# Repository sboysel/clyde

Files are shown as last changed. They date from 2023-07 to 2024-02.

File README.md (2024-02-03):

# clyde




- split ortholinear
- MX 36 keys (layout inspired by [weteor/Kong](https://github.com/weteor/Kong))
- RJ45 split comms
- WeAct RP2040 Pi Pico
- PCB: diodeless, reversible, hotswap

See `BOM` for complete list of parts and relevant numbers. Gerbers for PCB and switch plate in `prod`. Outline for bottom plate in `ergogen/outlines`.

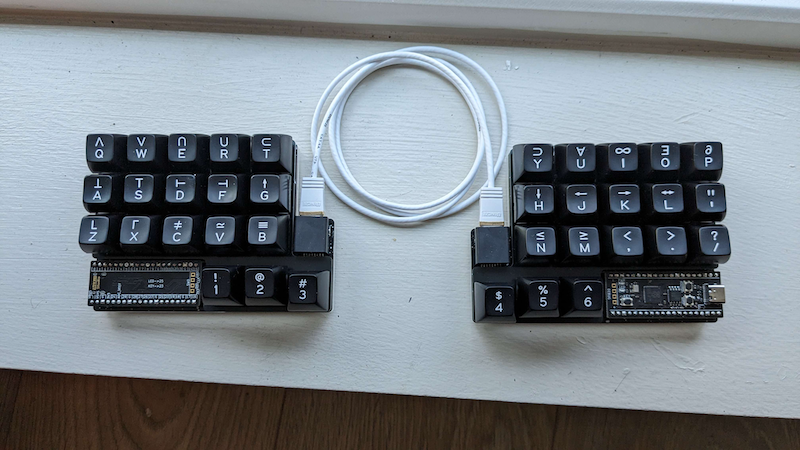
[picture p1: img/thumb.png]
clyde


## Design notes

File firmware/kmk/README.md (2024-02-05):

# clyde kmk firmware

1. copy CircuitPython to Pi Picos
2. rename L and R
    ```
    sudo umount /dev/sdb1
    sudo fatlabel /dev/sdb1 CLYDE36L
    ...
    ```
3. Use Piantor firmware as a starting point
    - https://raw.githubusercontent.com/cairnm/kmk_firmware/piantor/boards/beekeeb/piantor/kb.py
    - https://raw.githubusercontent.com/cairnm/kmk_firmware/piantor/boards/beekeeb/piantor/main.py 

## docs

- https://circuitpython.org/board/weact_studio_pico/
- http://kmkfw.io/docs/split_keyboards/

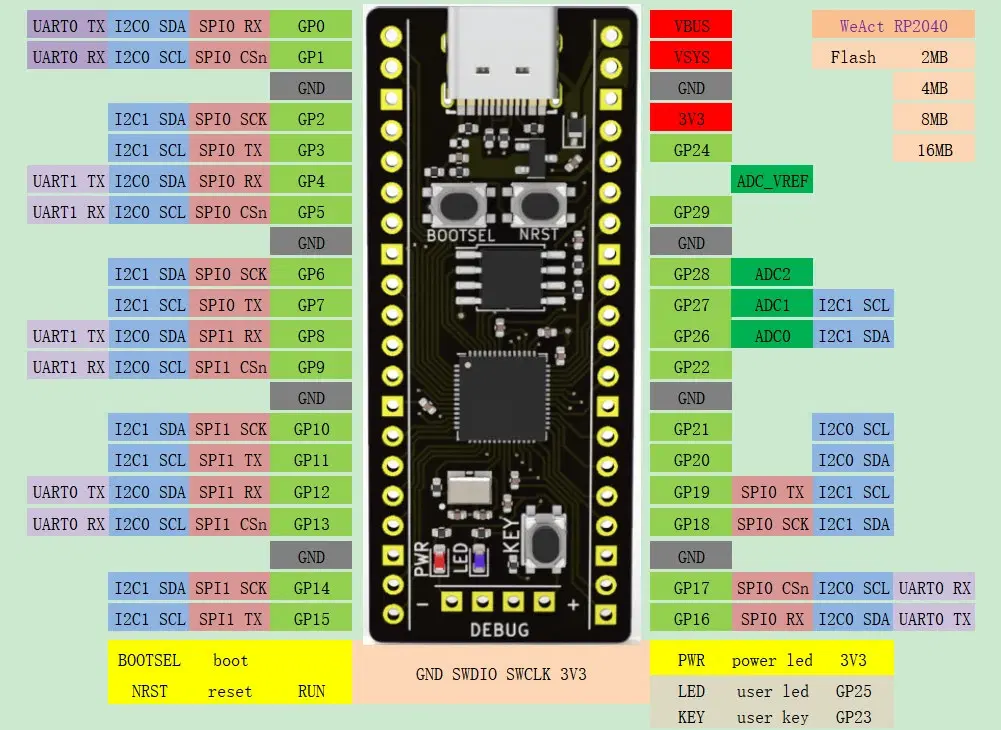
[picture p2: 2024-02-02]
img/WeAct_RP2040.jpg

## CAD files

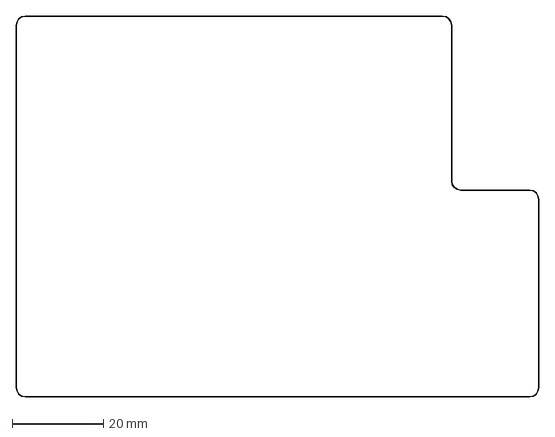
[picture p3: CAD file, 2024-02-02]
ergogen/outlines/clyde-pcb.dxf
114.3 x 83.3 mm

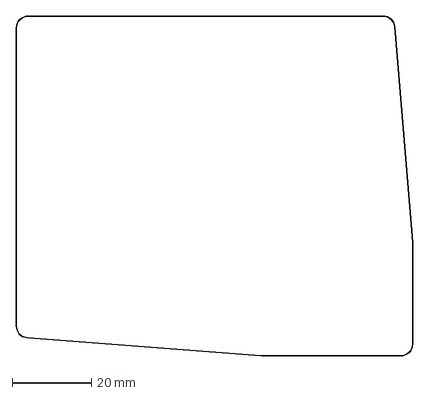
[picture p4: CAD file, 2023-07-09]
mx/outlines/clyde-mx-bottom-plate.dxf
100.0 x 85.7 mm

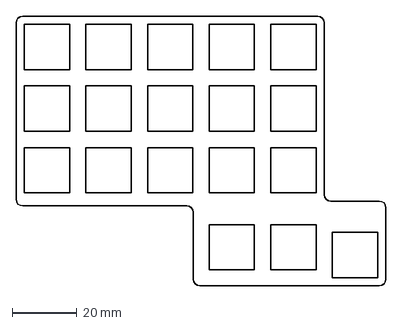
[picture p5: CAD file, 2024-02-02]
ergogen/outlines/clyde-switch-plate.dxf
114.3 x 83.3 mm

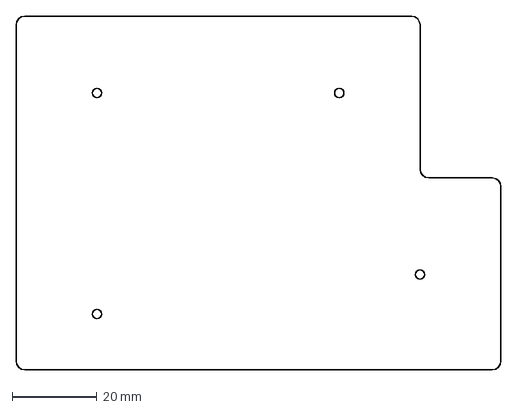
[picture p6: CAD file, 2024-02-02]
ergogen/outlines/clyde-bottom-plate.dxf
114.3 x 83.3 mm

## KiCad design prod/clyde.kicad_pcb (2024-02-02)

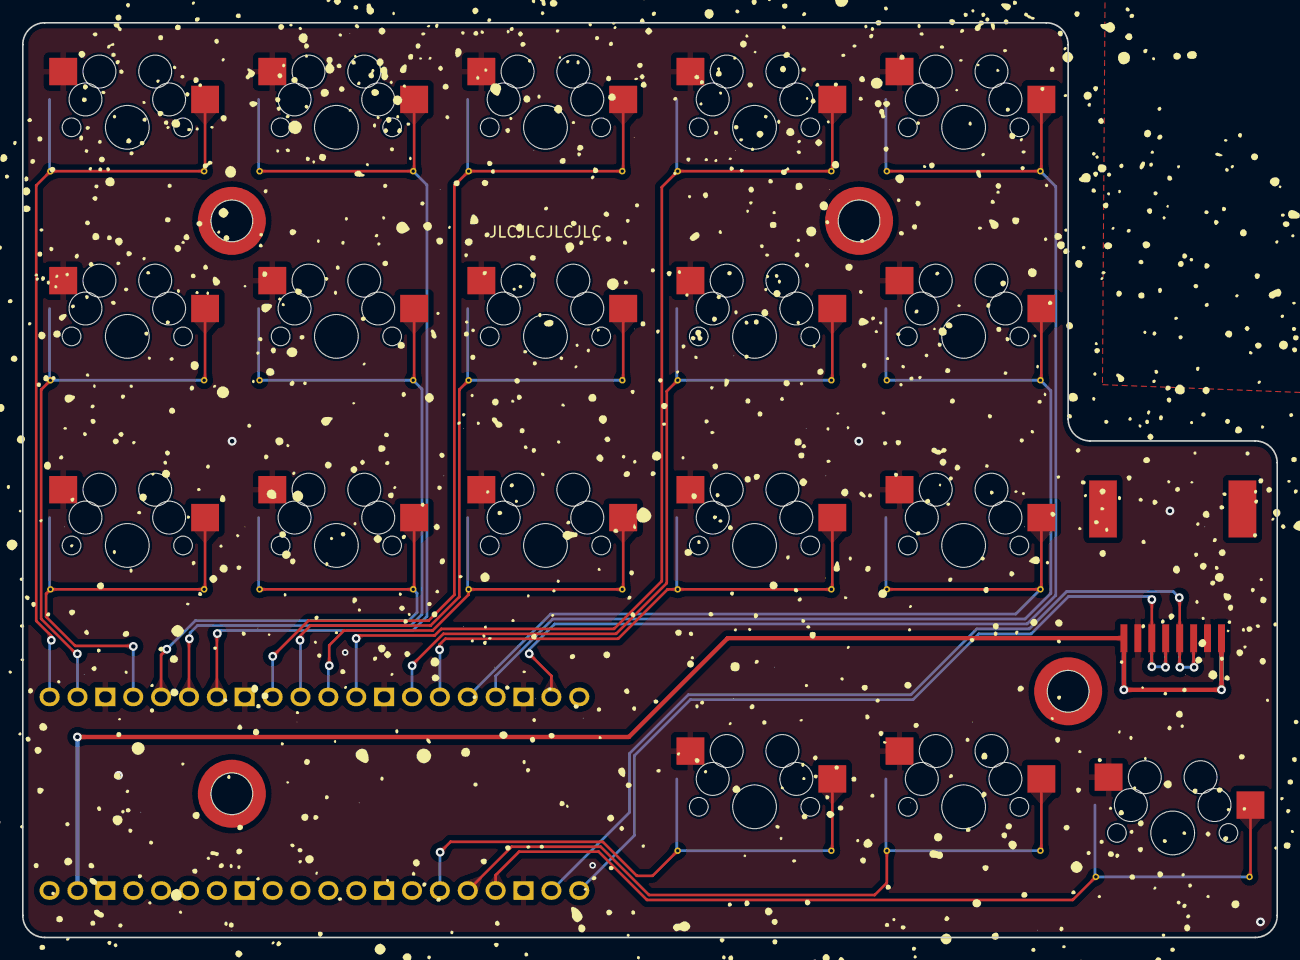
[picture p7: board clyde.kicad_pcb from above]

Board: 2 copper layers, 114.3 x 83.3 mm, 19 parts (0 on the bottom side), 19 nets.

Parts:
S1, S2, S3, S4, S5, S6, S7, S8, S9, S10, S11, S12, S13, S14, S15, S16, S17, S18: MX
U0: RPi_Pico_TH_oval_face_down

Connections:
GND: S1.2, S2.2, S3.2, S4.2, S5.2, S6.2, S7.2, S8.2, S9.2, S10.2, S11.2, S12.2, S13.2, S14.2, S15.2, S16.2, S17.2, S18.2, U0.3, U0.8, U0.13, U0.18, U0.23, U0.28, U0.33, U0.38
matrix_index_bottom: S10.1, U0.15
matrix_index_home: S11.1, U0.14
matrix_index_top: S12.1, U0.12
matrix_inner_bottom: S13.1, U0.16
matrix_inner_home: S14.1, U0.17
matrix_inner_top: S15.1, U0.19
matrix_middle_bottom: S7.1, U0.11
matrix_middle_home: S8.1, U0.10
matrix_middle_top: S9.1, U0.9
matrix_pinky_bottom: S1.1, U0.4
matrix_pinky_home: S2.1, U0.2
matrix_pinky_top: S3.1, U0.1
matrix_ring_bottom: S4.1, U0.5
matrix_ring_home: S5.1, U0.6
matrix_ring_top: S6.1, U0.7
thumb_far_mods: S18.1, U0.24
thumb_middle_mods: S17.1, U0.25
thumb_near_mods: S16.1, U0.26

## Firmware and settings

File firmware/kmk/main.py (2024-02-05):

import board

from kb import KMKKeyboard, isRight
keyboard = KMKKeyboard()

from kmk.keys import KC
from kmk.modules.split import Split, SplitSide, SplitType
from kmk.modules.layers import Layers; keyboard.modules.append(Layers())
from kmk.modules.modtap import ModTap; keyboard.modules.append(ModTap())
from kmk.modules.mouse_keys import MouseKeys; keyboard.modules.append(MouseKeys())
from kmk.modules.power import Power; keyboard.modules.append(Power())
from kmk.modules.tapdance import TapDance; keyboard.modules.append(TapDance())
from kmk.extensions.media_keys import MediaKeys; keyboard.extensions.append(MediaKeys())
from kmk.modules.capsword import CapsWord; keyboard.modules.append(CapsWord())

keyboard.tap_time = 100

split_side = SplitSide.RIGHT if isRight else SplitSide.LEFT

split = Split(
    split_side=split_side,
    split_type=SplitType.UART,
    split_flip=True,
    split_target_left=True,
    uart_flip=False,
    data_pin=board.GP17,
    data_pin2=board.GP16,
    use_pio=True,
)
keyboard.modules.append(split)


# === layer tap ---------------------------------------------------------------
# NAV (layer 1)
LT_TAB = KC.LT(1, KC.TAB, prefer_hold=True, tap_interrupted=False, tap_time=200)
LT_SPC = KC.LT(1, KC.SPC, prefer_hold=True, tap_interrupted=False, tap_time=200)
# NUM (layer 2)
LT_BSPC = KC.LT(2, KC.BSPC, prefer_hold=True, tap_interrupted=False, tap_time=200)
# SYM (layer 3)
LT_ENT = KC.LT(3, KC.ENT, prefer_hold=True, tap_interrupted=False, tap_time=200)
# FUN (layer 4)
LT_DEL = KC.LT(4, KC.DEL, prefer_hold=True, tap_interrupted=False, tap_time=200)
# MEDIA (layer 5)
LT_ESC = KC.LT(5, KC.ESC, prefer_hold=True, tap_interrupted=False, tap_time=200)

# === home row mods ------------------------------------------------------------
MT_A = KC.MT(KC.A, KC.LGUI, prefer_hold=False, tap_interrupted=True, tap_time=200)
MT_S = KC.MT(KC.S, KC.LALT, prefer_hold=False, tap_interrupted=True, tap_time=200)
MT_D = KC.MT(KC.D, KC.LCTL, prefer_hold=False, tap_interrupted=True, tap_time=200)
MT_F = KC.MT(KC.F, KC.LSFT, prefer_hold=False, tap_interrupted=True, tap_time=200)

MT_J = KC.MT(KC.J, KC.LSFT, prefer_hold=False, tap_interrupted=True, tap_time=200)
MT_K = KC.MT(KC.K, KC.LCTL, prefer_hold=False, tap_interrupted=True, tap_time=200)
MT_L = KC.MT(KC.L, KC.LALT, prefer_hold=False, tap_interrupted=True, tap_time=200)
MT_QUOT = KC.MT(KC.QUOT, KC.LGUI, prefer_hold=False, tap_interrupted=True, tap_time=200)

# === keymap -------------------------------------------------------------------
keyboard.keymap = [
    # QWERTY
    [
        KC.Q,    KC.W,    KC.E,    KC.R,    KC.T,       KC.Y,   KC.U,    KC.I,    KC.O,    KC.P,
        MT_A,    MT_S,    MT_D,    MT_F,    KC.G,       KC.H,   MT_J,    MT_K,    MT_L,    MT_QUOT,
        KC.Z,    KC.X,    KC.C,    KC.V,    KC.B,       KC.N,   KC.M,    KC.COMM, KC.DOT,  KC.SLSH,
                          LT_ESC,  LT_SPC,  LT_TAB,     LT_ENT, LT_BSPC, LT_DEL,
    ],                  
    #                     MEDIA             NAV         NUM     SYM      FUN
    # NAV
    [
        KC.NO,   KC.NO,   KC.NO,   KC.NO,   KC.NO,      KC.NO,  KC.NO,   KC.NO,   KC.NO,   KC.NO,
        KC.LGUI, KC.LALT, KC.LCTL, KC.LSFT, KC.NO,      KC.NO,  KC.LEFT, KC.DOWN, KC.UP,   KC.RGHT,
        KC.NO,   KC.RALT, KC.NO,   KC.NO,   KC.NO,      KC.INS, KC.HOME, KC.PGDN, KC.PGUP, KC.END,
                          KC.NO,   KC.NO,   KC.NO,      KC.ENT, KC.BSPC, KC.DEL, 
    ],
    # NUM
    [
        KC.LBRC, KC.N7,   KC.N8,   KC.N9,   KC.RBRC,    KC.NO,  KC.NO,   KC.NO,   KC.NO,   KC.NO,
        KC.SCLN, KC.N4,   KC.N5,   KC.N6,   KC.EQL,     KC.NO,  KC.LSFT, KC.LCTL, KC.LALT, KC.LGUI,
        KC.GRV,  KC.N1,   KC.N2,   KC.N3,   KC.BSLS,    KC.NO,  KC.NO,   KC.NO,   KC.RALT, KC.NO,
                          KC.DOT,  KC.N0,   KC.MINS,    KC.NO,  KC.NO,   KC.NO,
    ],
    # SYM
    [
        KC.LCBR, KC.AMPR, KC.ASTR, KC.LPRN, KC.RCBR,    KC.NO,  KC.NO,   KC.NO,   KC.NO,   KC.NO,
        KC.COLN, KC.DLR,  KC.PERC, KC.CIRC, KC.PLUS,    KC.NO,  KC.LSFT, KC.LCTL, KC.LALT, KC.LGUI,
        KC.TILD, KC.EXLM, KC.AT,   KC.HASH, KC.PIPE,    KC.NO,  KC.NO,   KC.NO,   KC.RALT, KC.NO,
                          KC.LPRN, KC.RPRN, KC.UNDS,    KC.NO,  KC.NO,   KC.NO,
    ],
    # FUN
    [
        KC.F12,  KC.F7,   KC.F8,   KC.F9,   KC.PSCR,    KC.NO,  KC.NO,   KC.NO,   KC.NO,   KC.NO,
        KC.F11,  KC.F4,   KC.F5,   KC.F6,   KC.SLCK,    KC.NO,  KC.LSFT, KC.LCTL, KC.LALT, KC.LGUI,
        KC.F10,  KC.F1,   KC.F2,   KC.F3,   KC.PAUS,    KC.NO,  KC.NO,   KC.NO,   KC.RALT, KC.NO,
                          KC.APP,  KC.SPC,  KC.TAB,     KC.NO,  KC.NO,   KC.NO,
    ],
    # MEDIA
    [
        KC.NO,   KC.NO,   KC.NO,   KC.NO,   KC.NO,      KC.NO,     KC.NO,   KC.NO,   KC.NO,   KC.NO,
        KC.LGUI, KC.LALT, KC.LCTL, KC.LSFT, KC.NO,      KC.PS_TOG, KC.MPRV, KC.VOLD, KC.VOLU, KC.MNXT,
        KC.NO,   KC.RALT, KC.NO,   KC.NO,   KC.NO,      KC.HID,    KC.NO,   KC.NO,   KC.NO,   KC.NO,
                          KC.NO,   KC.NO,   KC.NO,      KC.MSTP,   KC.MPLY, KC.MUTE,
    ],
]

layer_names_list = [
    'QWERTY', 'NAV', 'NUM', 'SYM', 'FUN', 'MEDIA',
]

if __name__ == '__main__':
    keyboard.go()

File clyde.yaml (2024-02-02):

meta:
  engine: 4.0.4
  name: clyde
  version: 1.0.0
  author: sboysel
  url: https://github.com/sboysel/clyde

units:
  kx: U
  ky: U
  px: 0.5kx
  py: 0.5ky
  tx: 0
  ty: 0.25ky
  ts: 0.125ky
  vx: 7
  vy: -4
  pcb_fillet: 2
  case_fillet: 2
  case_thickness: 6

points:
  zones:
    matrix:
      anchor:
        shift: [8kx, -8ky]
      columns:
        pinky:
        ring:
        middle:
        index:
        inner:
      rows:
        bottom:
        home:
        top:
    thumb:
      anchor:
        ref: matrix_index_bottom
        shift: [tx, -1ky - ty]
      columns:
        near:
        middle:
        far:
          key:
            stagger: -ts
      rows:
        mods:
  key:
    padding: 1ky
    spread: 1kx

outlines:
  _pcb:
    - what: polygon
      points:
        # NW
        - ref: matrix_pinky_top
          shift: [-px, py]
        # NE
        - ref: matrix_inner_top
          shift: [px, py]
        # E
        - ref: matrix_inner_bottom
          shift: [px, py]
        - ref: matrix_inner_bottom
          shift: [px + kx, py]
        # SE
        - ref: thumb_far_mods
          shift: [px, -py]
        - ref: thumb_near_mods
          shift: [-px, -py - ts]
        # SW
        - ref: matrix_pinky_bottom
          shift: [-px, -ky - ty - py - ts]
  _plate:
    - what: polygon
      points:
        # NW
        - ref: matrix_pinky_top
          shift: [-px, py]
        # NE
        - ref: matrix_inner_top
          shift: [px, py]
        # E
        - ref: matrix_inner_bottom
          shift: [px, -py]
        - ref: matrix_inner_bottom
          shift: [px + kx, -py]
        # SE
        - ref: thumb_far_mods
          shift: [px, -py]
        - ref: thumb_near_mods
          shift: [-px - ts, -py - ts]
        - ref: matrix_middle_bottom
          shift: [px - ts, -py - 1.5]
        # SW
        - ref: matrix_pinky_bottom
          shift: [-px, -py - 1.5]
      fillet: pcb_fillet
  clyde-pcb:
    - what: outline
      name: _pcb
      fillet: pcb_fillet
  _switches:
    - what: rectangle
      where: true
      size: 14
      bound: false
  clyde-switch-plate:
    - _plate
    - -_switches
  _m0:
    - what: circle
      where:
        ref: matrix_pinky_home
        shift: [px, py + 1]
      radius: 1.1
  _m1:
    - what: circle
      where:
        ref: matrix_index_home
        shift: [px, py + 1]
      radius: 1.1
  _m2:
    - what: circle
      where:
        ref: thumb_middle_mods
        shift: [px, py + 1]
      radius: 1.1
  _m3:
    - what: circle
      where:
        ref: matrix_pinky_bottom
        shift: [px, -py - (ky + ty + ts) / 2]
      radius: 1.1
  clyde-bottom-plate:
    - clyde-pcb
    - -_m0
    - -_m1
    - -_m2
    - -_m3
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

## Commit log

2024-02-02 v1 (#1)
    * 36 key version
    * layout like split weteor/Kong; outline tweaks
    * rj45, PCB solder nuts, acrylic bottom plate
    * JLCPCB prototypes received and operational
    [clyde-bottom-plate.dxf, clyde-mx.kicad_pcb, clyde-pcb.dxf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]
2024-02-03 add BOM

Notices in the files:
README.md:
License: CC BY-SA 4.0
